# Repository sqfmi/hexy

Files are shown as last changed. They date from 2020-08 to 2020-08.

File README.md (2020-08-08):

# Hexy

Inspired by [Mukesh Sankhla](https://www.youtube.com/c/MukeshSankhla)'s [HexMatrix](https://hackaday.io/project/173732-rgb-hexmatrix-iot-clock) project, this is a smaller version using 96 3.5x3.5MM RGB LEDs ([WS2812B-MINI](https://www.adafruit.com/product/2659))

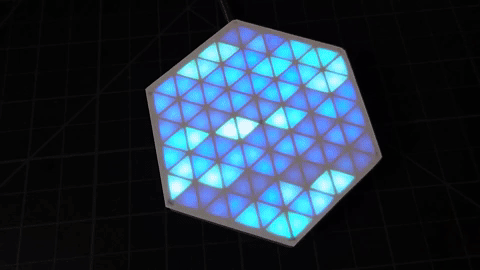
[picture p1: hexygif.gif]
hexy


## Hardware
All KiCad design files under MIT license

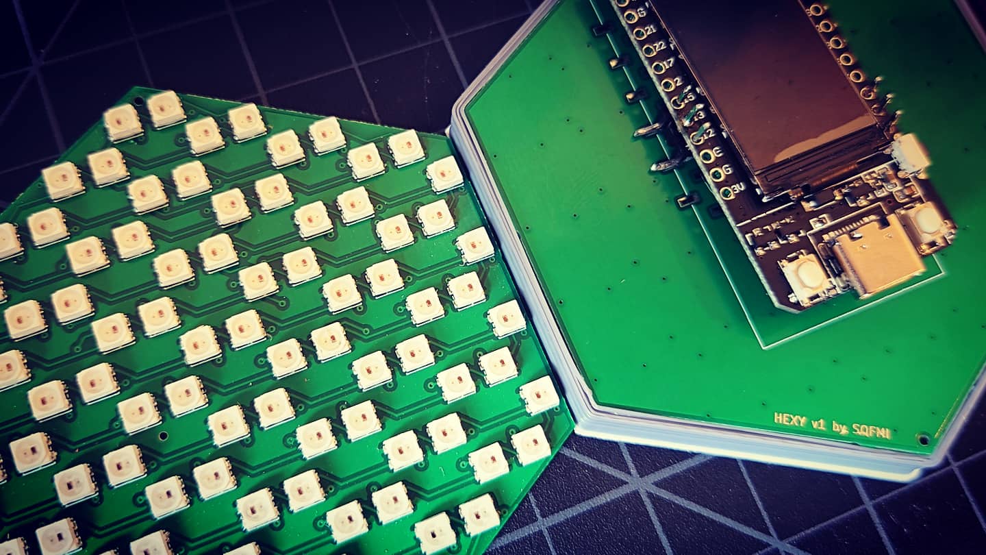
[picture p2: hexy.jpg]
Hexy running the Pacific demo in the FastLED library


### BOM
- 1 x PCB
- 96 x [WS2812B-MINI](https://www.adafruit.com/product/2659)
- 1 x [TTGO T-DISPLAY](https://www.aliexpress.com/item/33048962331.html) (or any other microcontroller)
- 2 x [2.54MM SMD Pin Headers](https://www.digikey.com/product-detail/en/amphenol-icc-fci/10129380-906001ALF/609-10129380-906001ALFCT-ND/11630008) (You only need 3 pins connected i.e. DIN/VCC/GND but using a full row of 12 pins will mount more securely)

### Wiring Pattern
The LEDs are laid out in a zigzag pattern:

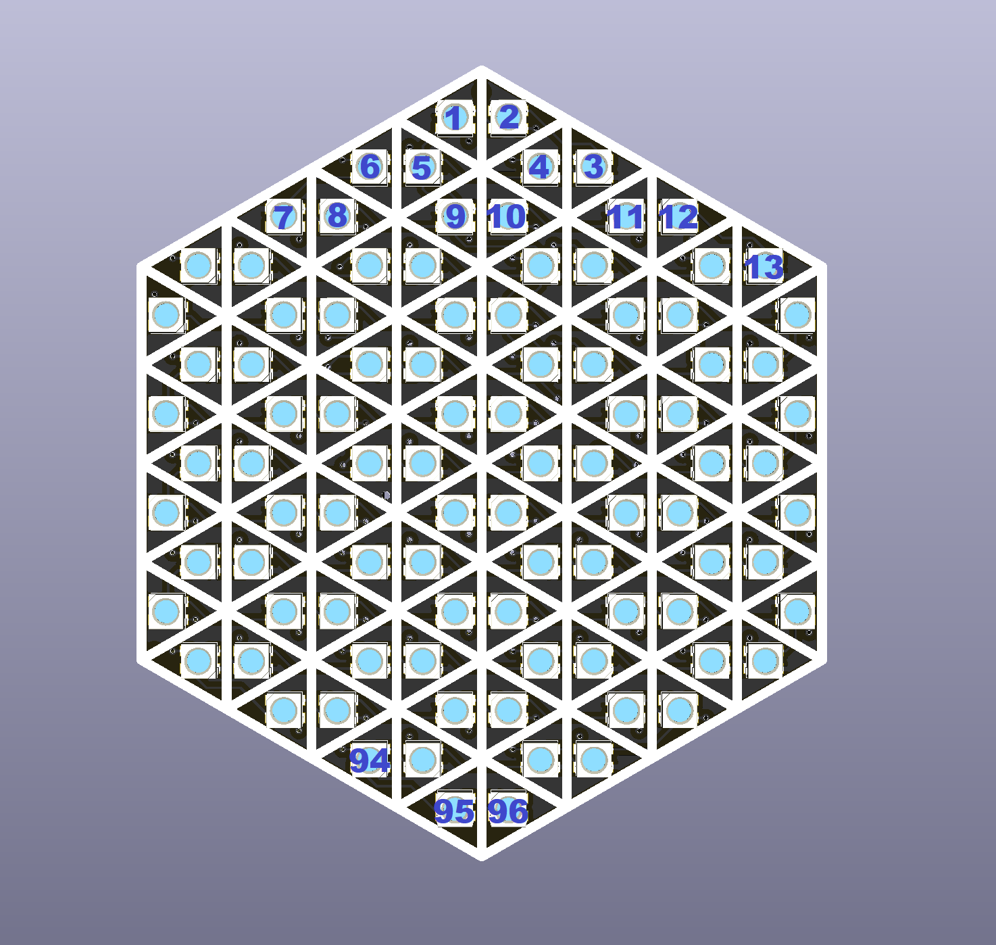
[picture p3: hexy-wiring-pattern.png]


## Software
We used the [FastLED](https://github.com/FastLED/FastLED) library v3.3
- Set the data pin to **13** (or any other pin if you are using another microcontroller)
- Set the number of LEDs to **96**
- Set the LED Chipset to **WS2812B**

## Frame
For best visual results, 3D print the seperator grid [hexy-frame.stl](hexy-frame.stl) to keep the light from bleeding over. You will also need a piece of paper/acrylic glued on top to diffuse the light so each triangle cell looks nice and crisp [hexy-diffusion.dxf](hexy-diffusion.dxf)

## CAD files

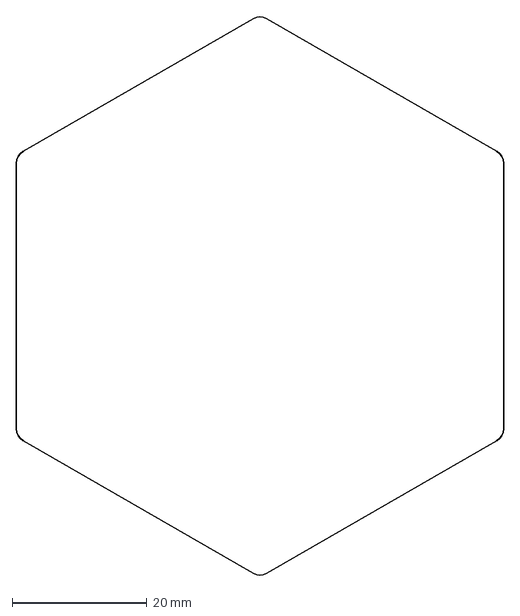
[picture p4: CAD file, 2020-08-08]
hexy-diffusion.dxf
72.3 x 83.0 mm

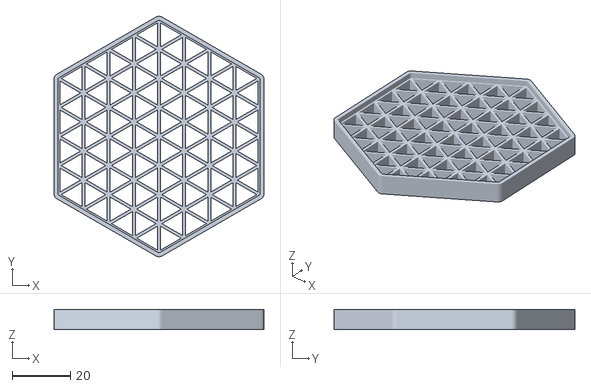
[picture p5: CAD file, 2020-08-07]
hexy-frame.stl
72.3 x 82.8 x 7.00

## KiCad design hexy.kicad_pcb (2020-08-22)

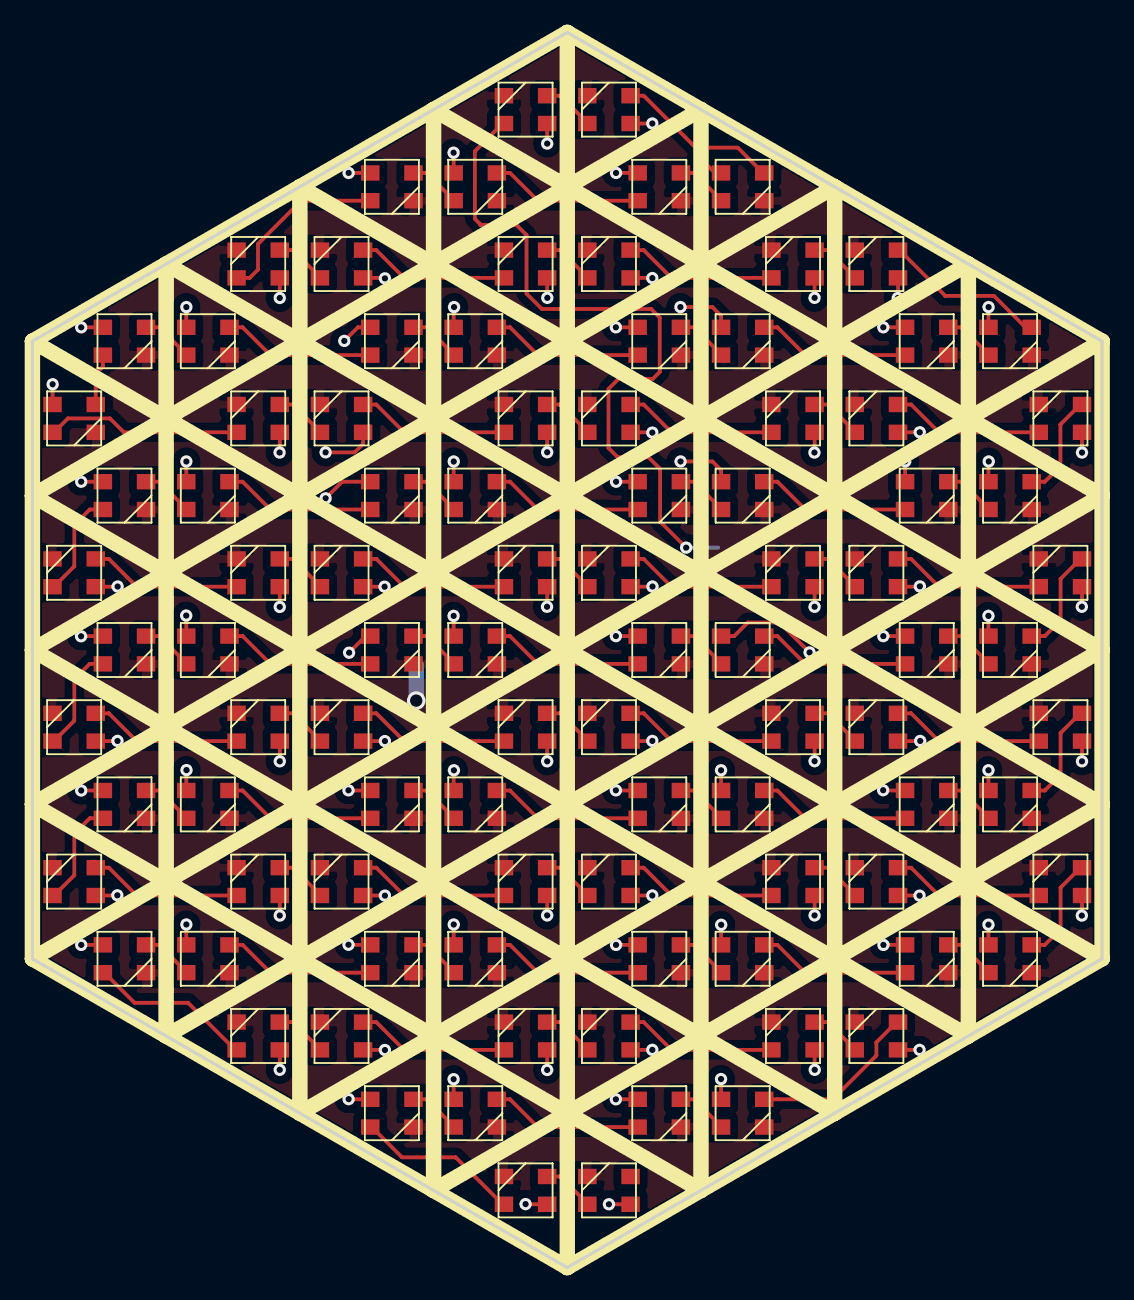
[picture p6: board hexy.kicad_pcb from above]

Board: 2 copper layers, 69.3 x 80.0 mm, 97 parts (1 on the bottom side), 98 nets.

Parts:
D1, D2, D3, D4, D5, D6, D7, D8, D9, D10, D11, D12, D13, D14, D15, D16, D17, D18, D19, D20, D21, D22, D23, D24, D25, D26, D27, D28, D29, D30, D31, D32, D33, D34, D35, D36, D37, D38, D39, D40, D41, D42, D43, D44, D45, D46, D47, D48, D49, D50, D51, D52, D53, D54, D55, D56, D57, D58, D59, D60, D61, D62, D63, D64, D65, D66, D67, D68, D69, D70, D71, D72, D73, D74, D75, D76, D77, D78, D79, D80, D81, D82, D83, D84, D85, D86, D87, D88, D89, D90, D91, D92, D93, D94, D95, D96: WS2812B; WS2812B-MINI
TTGO T-DISPLAY: TTGO_T-DISPLAY; TTGO_T-DISPLAY_SMD

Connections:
DIN: D1.4, TTGO T-DISPLAY.8
GND: D1.3, D2.3, D3.3, D4.3, D5.3, D6.3, D7.3, D8.3, D9.3, D10.3, D11.3, D12.3, D13.3, D14.3, D15.3, D16.3, D17.3, D18.3, D19.3, D20.3, D21.3, D22.3, D23.3, D24.3, D25.3, D26.3, D27.3, D28.3, D29.3, D30.3, D31.3, D32.3, D33.3, D34.3, D35.3, D36.3, D37.3, D38.3, D39.3, D40.3, D41.3, D42.3, D43.3, D44.3, D45.3, D46.3, D47.3, D48.3, D49.3, D50.3, D51.3, D52.3, D53.3, D54.3, D55.3, D56.3, D57.3, D58.3, D59.3, D60.3, D61.3, D62.3, D63.3, D64.3, D65.3, D66.3, D67.3, D68.3, D69.3, D70.3, D71.3, D72.3, D73.3, D74.3, D75.3, D76.3, D77.3, D78.3, D79.3, D80.3, D81.3, D82.3, D83.3, D84.3, D85.3, D86.3, D87.3, D88.3, D89.3, D90.3, D91.3, D92.3, D93.3, D94.3, D95.3, D96.3, TTGO T-DISPLAY.14
unnamed: D1.2, D2.4
unnamed: D2.2, D3.4
unnamed: D3.2, D4.4
unnamed: D4.2, D5.4
unnamed: D5.2, D6.4
unnamed: D6.2, D7.4
unnamed: D7.2, D8.4
unnamed: D8.2, D9.4
unnamed: D10.2, D11.4
unnamed: D9.2, D10.4
unnamed: D11.2, D12.4
unnamed: D12.2, D13.4
unnamed: D13.2, D14.4
unnamed: D14.2, D15.4
unnamed: D15.2, D16.4
unnamed: D16.2, D17.4
unnamed: D17.2, D18.4
unnamed: D18.2, D19.4
unnamed: D19.2, D20.4
unnamed: D20.2, D21.4
unnamed: D21.2, D22.4
unnamed: D22.2, D23.4
unnamed: D23.2, D24.4
unnamed: D24.2, D25.4
unnamed: D25.2, D26.4
unnamed: D26.2, D27.4
unnamed: D27.2, D28.4
unnamed: D28.2, D29.4
unnamed: D29.2, D30.4
unnamed: D30.2, D31.4
unnamed: D31.2, D32.4
unnamed: D32.2, D33.4
unnamed: D33.2, D34.4
unnamed: D34.2, D35.4
unnamed: D35.2, D36.4
unnamed: D36.2, D37.4
unnamed: D37.2, D38.4
unnamed: D38.2, D39.4
unnamed: D39.2, D40.4
unnamed: D40.2, D41.4
unnamed: D41.2, D42.4
unnamed: D42.2, D43.4
unnamed: D43.2, D44.4
unnamed: D44.2, D45.4
unnamed: D45.2, D46.4
unnamed: D46.2, D47.4
unnamed: D47.2, D48.4
unnamed: D48.2, D49.4
unnamed: D49.2, D50.4
unnamed: D50.2, D51.4
unnamed: D51.2, D52.4
unnamed: D52.2, D53.4
unnamed: D53.2, D54.4
unnamed: D54.2, D55.4
unnamed: D55.2, D56.4
unnamed: D56.2, D57.4
unnamed: D57.2, D58.4
unnamed: D58.2, D59.4
unnamed: D59.2, D60.4
unnamed: D60.2, D61.4
unnamed: D61.2, D62.4
unnamed: D62.2, D63.4
unnamed: D63.2, D64.4
unnamed: D64.2, D65.4
unnamed: D65.2, D66.4
unnamed: D66.2, D67.4
unnamed: D67.2, D68.4
unnamed: D68.2, D69.4
unnamed: D69.2, D70.4
unnamed: D70.2, D71.4
unnamed: D71.2, D72.4
unnamed: D72.2, D73.4
unnamed: D73.2, D74.4
unnamed: D74.2, D75.4
unnamed: D75.2, D76.4
unnamed: D76.2, D77.4
unnamed: D77.2, D78.4
unnamed: D78.2, D79.4
unnamed: D79.2, D80.4
unnamed: D80.2, D81.4
unnamed: D81.2, D82.4
unnamed: D82.2, D83.4
unnamed: D83.2, D84.4
unnamed: D84.2, D85.4
unnamed: D85.2, D86.4
unnamed: D86.2, D87.4
unnamed: D87.2, D88.4
unnamed: D88.2, D89.4
unnamed: D89.2, D90.4
unnamed: D90.2, D91.4
unnamed: D91.2, D92.4
unnamed: D92.2, D93.4
unnamed: D93.2, D94.4
unnamed: D94.2, D95.4
unnamed: D95.2, D96.4
VCC: D1.1, D2.1, D3.1, D4.1, D5.1, D6.1, D7.1, D8.1, D9.1, D10.1, D11.1, D12.1, D13.1, D14.1, D15.1, D16.1, D17.1, D18.1, D19.1, D20.1, D21.1, D22.1, D23.1, D24.1, D25.1, D26.1, D27.1, D28.1, D29.1, D30.1, D31.1, D32.1, D33.1, D34.1, D35.1, D36.1, D37.1, D38.1, D39.1, D40.1, D41.1, D42.1, D43.1, D44.1, D45.1, D46.1, D47.1, D48.1, D49.1, D50.1, D51.1, D52.1, D53.1, D54.1, D55.1, D56.1, D57.1, D58.1, D59.1, D60.1, D61.1, D62.1, D63.1, D64.1, D65.1, D66.1, D67.1, D68.1, D69.1, D70.1, D71.1, D72.1, D73.1, D74.1, D75.1, D76.1, D77.1, D78.1, D79.1, D80.1, D81.1, D82.1, D83.1, D84.1, D85.1, D86.1, D87.1, D88.1, D89.1, D90.1, D91.1, D92.1, D93.1, D94.1, D95.1, D96.1, TTGO T-DISPLAY.13
